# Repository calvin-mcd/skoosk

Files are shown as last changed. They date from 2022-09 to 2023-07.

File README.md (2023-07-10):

# skoosk

some kind of ortholinear split keyboard

The skoosk was my first attempt at creating a split ortholinear keyboard from scratch. The first production run had some issues with the pcb and the plate files. In the process of rectifying these issues I ended up creating simplifying the pcb for manual assembly. There are two different types of switch and backplates. One for more bounce, the other for more stability.

## Layout

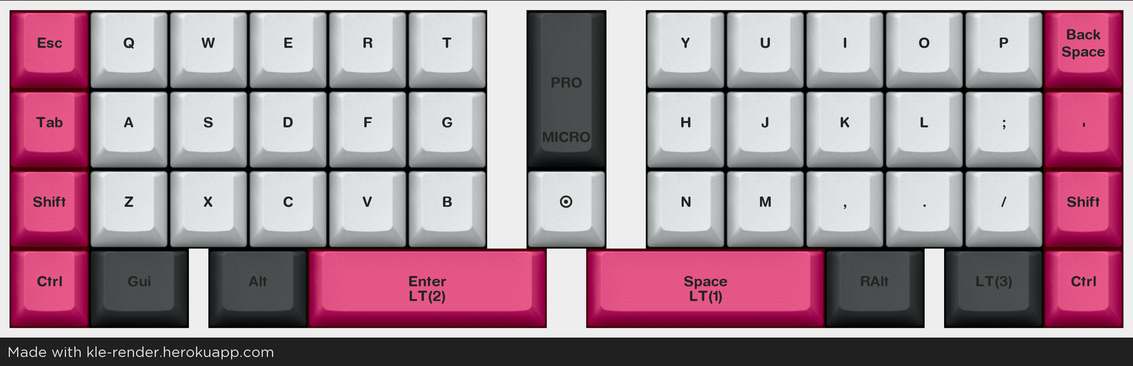
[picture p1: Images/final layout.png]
 

<a href="https://www.keyboard-layout-editor.com/#/gists/cdc0d16012a44037b1bdb8499f2bf92a">Link<a>

## Pictures

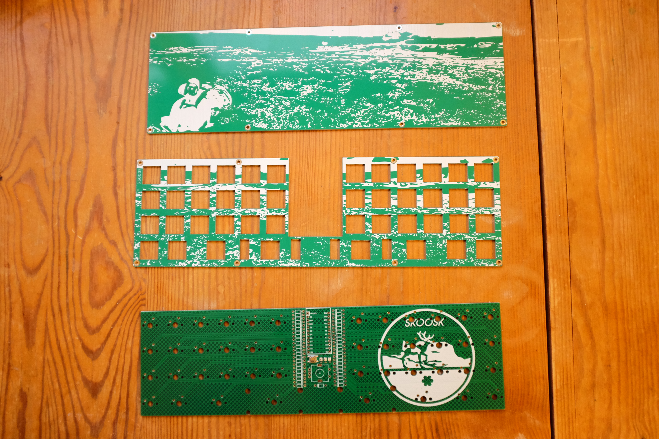
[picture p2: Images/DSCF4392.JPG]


## Project Files

*skoosk pcb rgb* is not designed for manual assembly supporting LEDs and a reset switch if wanted.

*skoosk switchplate & backplate 4 screwholes* each have 4 outer screwholes that give the sandwhich assembly a good amount of bounce.

*skoosk switchplate & backplate 8 screwholes* have 8 screwholes in total to offer more stability for the whole sandwhich case.

## Todo
- [ ] test newest pcb revision
- [ ] add firmware support for the RGB indicator leds

## Disclaimer

Please note that this project has not been tested in its final version. There are no guarantees of a working outcome. No-one involved in this project is responsible for any usage issues that may arise. However, feel free to edit, modify and otherwise utilise these files.

## License

This project is released under the GPL v3 License. Please refer to the LICENCE file.

## Credits

As always big thanks to the many people who helped me with the pcb, firmware and much more! 

Any questions, contact Calvin#0563 on Discord.

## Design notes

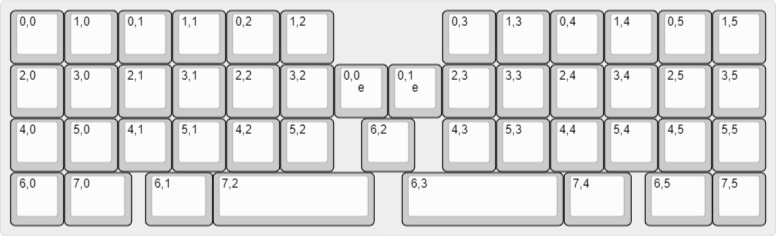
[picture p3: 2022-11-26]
Firmware/Images/updated-keyboard-layout.png

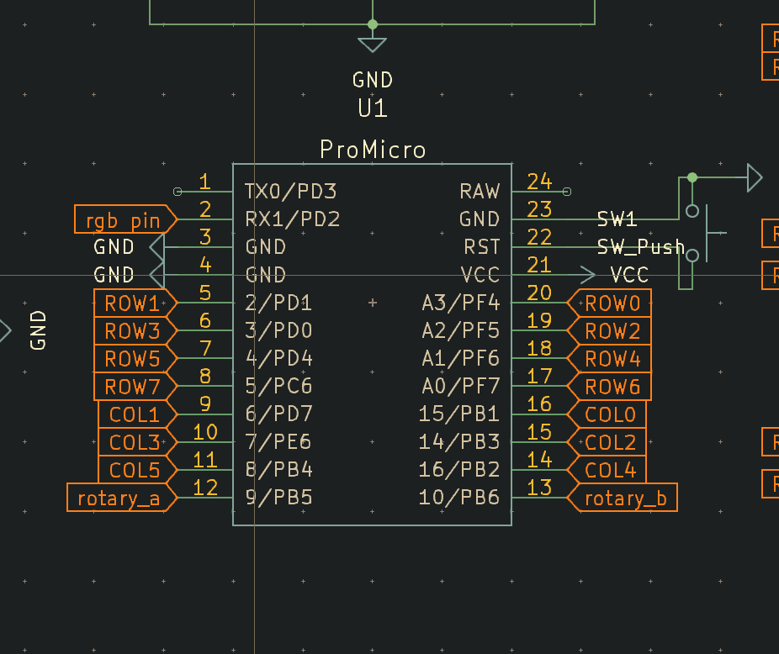
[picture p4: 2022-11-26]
Firmware/Images/mcu.png

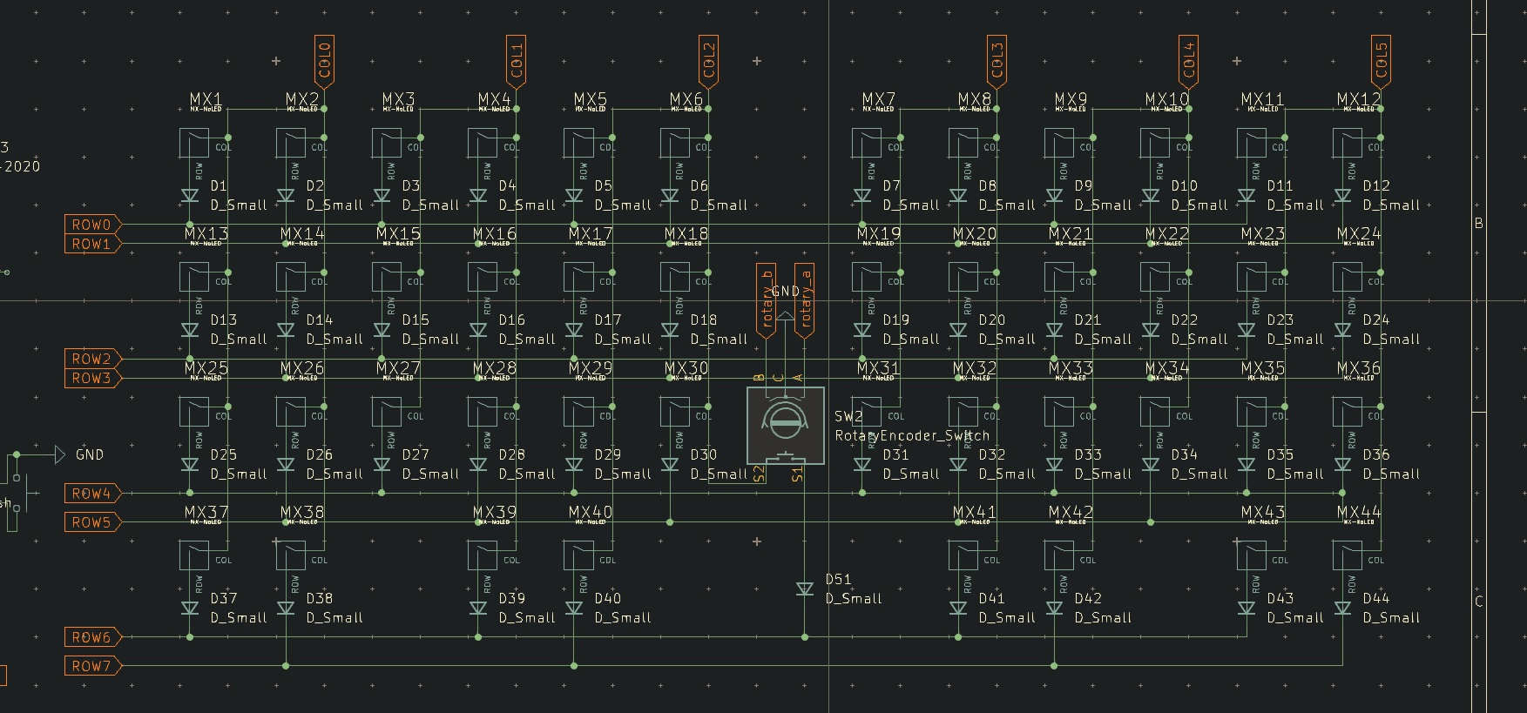
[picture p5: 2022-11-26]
Firmware/Images/matrix.jpg

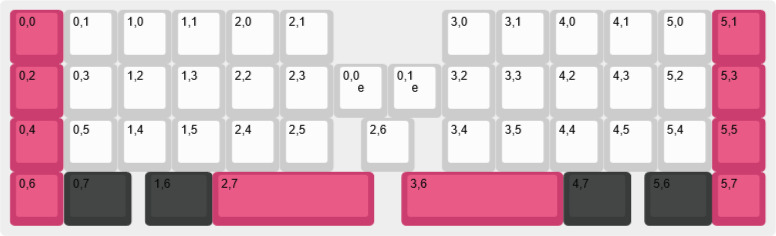
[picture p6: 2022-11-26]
Firmware/Images/keyboard-layout.jpg

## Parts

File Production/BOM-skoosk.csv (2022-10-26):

Comment | Designator | Footprint | LCSC
1uF | Crgb1,Crgb2,Crgb3 | C_0402_1005Metric | C14445
SW_Push | SW1 | SKQG-1155865 | C318884
WS2812-2020 | Drgb1,Drgb2,Drgb3 | WS2812-2020 | C965555

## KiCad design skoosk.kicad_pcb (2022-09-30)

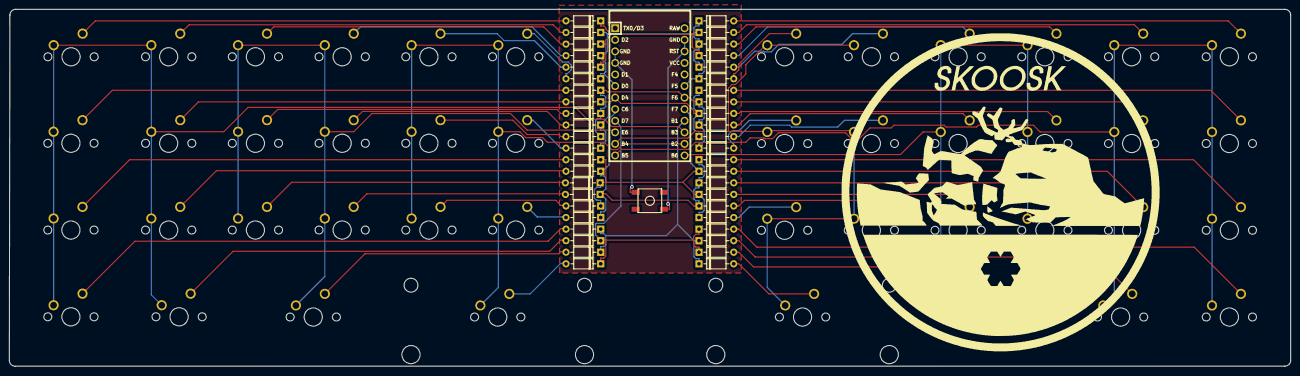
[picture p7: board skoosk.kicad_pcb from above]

Board: 2 copper layers, 281.4 x 78.4 mm, 92 parts (1 on the bottom side), 60 nets.

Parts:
D1, D2, D3, D4, D5, D6, D7, D8, D9, D10, D11, D12, D13, D14, D15, D16, D17, D18, D19, D20, D21, D22, D23, D24, D25, D26, D27, D28, D29, D30, D31, D32, D33, D34, D35, D36, D37, D38, D39, D40, D41, D42, D43, D44: D_Small; D_DO-35_SOD27_P7.62mm_Horizontal
Gback: LOGO
Gfront: LOGO
MX1, MX12, MX13, MX24, MX25, MX36, MX37, MX38, MX39, MX42, MX43, MX44: MX-NoLED; MXOnly-1.25U-NoLED
MX2, MX3, MX4, MX5, MX6, MX7, MX8, MX9, MX10, MX11, MX14, MX15, MX16, MX17, MX18, MX19, MX20, MX21, MX22, MX23, MX26, MX27, MX28, MX29, MX30, MX31, MX32, MX33, MX34, MX35: MX-NoLED; MXOnly-1U-NoLED
MX40, MX41: MX-NoLED; MXOnly-3U-NoLED
SW1: SW_Push; SKQG-1155865
U1: ProMicro; ArduinoProMicro

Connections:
COL0: MX1.1 (COL), MX2.1 (COL), MX13.1 (COL), MX14.1 (COL), MX25.1 (COL), MX26.1 (COL), MX37.1 (COL), MX38.1 (COL), U1.15 (14/PB3)
COL1: MX3.1 (COL), MX4.1 (COL), MX15.1 (COL), MX16.1 (COL), MX27.1 (COL), MX28.1 (COL), MX39.1 (COL), U1.10 (7/PE6)
COL2: MX5.1 (COL), MX6.1 (COL), MX17.1 (COL), MX18.1 (COL), MX29.1 (COL), MX30.1 (COL), MX40.1 (COL), U1.14 (16/PB2)
COL3: MX7.1 (COL), MX8.1 (COL), MX19.1 (COL), MX20.1 (COL), MX31.1 (COL), MX32.1 (COL), MX41.1 (COL), U1.11 (8/PB4)
COL4: MX9.1 (COL), MX10.1 (COL), MX21.1 (COL), MX22.1 (COL), MX33.1 (COL), MX34.1 (COL), MX42.1 (COL), U1.13 (10/PB6)
COL5: MX11.1 (COL), MX12.1 (COL), MX23.1 (COL), MX24.1 (COL), MX35.1 (COL), MX36.1 (COL), MX43.1 (COL), MX44.1 (COL), U1.12 (9/PB5)
GND: SW1.2, U1.3 (GND), U1.4 (GND)
unnamed: D1.2 (A), MX1.2 (ROW)
unnamed: D2.2 (A), MX2.2 (ROW)
unnamed: D3.2 (A), MX3.2 (ROW)
unnamed: D4.2 (A), MX4.2 (ROW)
unnamed: D5.2 (A), MX5.2 (ROW)
unnamed: D6.2 (A), MX6.2 (ROW)
unnamed: D7.2 (A), MX7.2 (ROW)
unnamed: D8.2 (A), MX8.2 (ROW)
unnamed: D9.2 (A), MX9.2 (ROW)
unnamed: D10.2 (A), MX10.2 (ROW)
unnamed: D11.2 (A), MX11.2 (ROW)
unnamed: D12.2 (A), MX12.2 (ROW)
unnamed: D13.2 (A), MX13.2 (ROW)
unnamed: D14.2 (A), MX14.2 (ROW)
unnamed: D15.2 (A), MX15.2 (ROW)
unnamed: D16.2 (A), MX16.2 (ROW)
unnamed: D17.2 (A), MX17.2 (ROW)
unnamed: D18.2 (A), MX18.2 (ROW)
unnamed: D19.2 (A), MX19.2 (ROW)
unnamed: D20.2 (A), MX20.2 (ROW)
unnamed: D21.2 (A), MX21.2 (ROW)
unnamed: D22.2 (A), MX22.2 (ROW)
unnamed: D23.2 (A), MX23.2 (ROW)
unnamed: D24.2 (A), MX24.2 (ROW)
unnamed: D25.2 (A), MX25.2 (ROW)
unnamed: D26.2 (A), MX26.2 (ROW)
unnamed: D27.2 (A), MX27.2 (ROW)
unnamed: D28.2 (A), MX28.2 (ROW)
unnamed: D29.2 (A), MX29.2 (ROW)
unnamed: D30.2 (A), MX30.2 (ROW)
unnamed: D31.2 (A), MX31.2 (ROW)
unnamed: D32.2 (A), MX32.2 (ROW)
unnamed: D33.2 (A), MX33.2 (ROW)
unnamed: D34.2 (A), MX34.2 (ROW)
unnamed: D35.2 (A), MX35.2 (ROW)
unnamed: D36.2 (A), MX36.2 (ROW)
unnamed: D37.2 (A), MX37.2 (ROW)
unnamed: D38.2 (A), MX38.2 (ROW)
unnamed: D39.2 (A), MX39.2 (ROW)
unnamed: D40.2 (A), MX40.2 (ROW)
unnamed: D41.2 (A), MX41.2 (ROW)
unnamed: D42.2 (A), MX42.2 (ROW)
unnamed: D43.2 (A), MX43.2 (ROW)
unnamed: D44.2 (A), MX44.2 (ROW)
unnamed: SW1.1, U1.22 (RST), U1.23 (GND)
ROW0: D1.1 (K), D3.1 (K), D5.1 (K), D7.1 (K), D9.1 (K), D11.1 (K), U1.19 (A2/PF5)
ROW1: D2.1 (K), D4.1 (K), D6.1 (K), D8.1 (K), D10.1 (K), D12.1 (K), U1.6 (3/PD0)
ROW2: D13.1 (K), D15.1 (K), D17.1 (K), D19.1 (K), D21.1 (K), D23.1 (K), U1.18 (A1/PF6)
ROW3: D14.1 (K), D16.1 (K), D18.1 (K), D20.1 (K), D22.1 (K), D24.1 (K), U1.7 (4/PD4)
ROW4: D25.1 (K), D27.1 (K), D29.1 (K), D31.1 (K), D33.1 (K), D35.1 (K), U1.17 (A0/PF7)
ROW5: D26.1 (K), D28.1 (K), D30.1 (K), D32.1 (K), D34.1 (K), D36.1 (K), U1.8 (5/PC6)
ROW6: D37.1 (K), D39.1 (K), D41.1 (K), D43.1 (K), U1.16 (15/PB1)
ROW7: D38.1 (K), D40.1 (K), D42.1 (K), D44.1 (K), U1.9 (6/PD7)

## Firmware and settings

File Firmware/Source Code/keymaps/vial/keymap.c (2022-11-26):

#include QMK_KEYBOARD_H

const uint16_t PROGMEM keymaps[][MATRIX_ROWS][MATRIX_COLS] = {
    [0] = LAYOUT(
        KC_NO,   KC_NO,   KC_NO,   KC_NO,   KC_NO,   KC_NO,
        KC_NO,   KC_NO,   KC_NO,   KC_NO,   KC_NO,   KC_NO,
        KC_NO,   KC_NO,   KC_NO,   KC_NO,   KC_NO,   KC_NO,
        KC_NO,   KC_NO,   KC_NO,   KC_NO,   KC_NO,   KC_NO,
        KC_NO,   KC_NO,   KC_NO,   KC_NO,   KC_NO,   KC_NO,
        KC_NO,   KC_NO,   KC_NO,   KC_NO,   KC_NO,   KC_NO,
        KC_NO,   KC_NO,   KC_NO,   KC_NO,            KC_NO,
        KC_NO,            KC_NO,            KC_NO,   KC_NO
    ),		
};

/* Encoder */ 
const uint16_t PROGMEM encoder_map[][NUM_ENCODERS][2] = {
    [0] = { ENCODER_CCW_CW(KC_TRNS, KC_TRNS) }
};

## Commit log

2022-09-29 Add submodules
    [skoosk.kicad_pcb, skoosk.kicad_sch]
2022-09-29 adding libraries
    [skoosk.kicad_sch]
2022-09-29 switch matrix build, footprints layed out
    missing is MCU footprint, reset switch, traces
    do i want underglow?
    [skoosk.kicad_pcb, skoosk.kicad_sch]
2022-09-29 all switches and diodes placed
    next change mcu for usb c, figure out a reset button
    [skoosk.kicad_pcb, skoosk.kicad_sch]
2022-09-29 tracing col and rows
    [skoosk.kicad_pcb, skoosk.kicad_sch]
2022-09-30 saving before doing autorouting
    [skoosk.kicad_pcb, skoosk.kicad_sch]
2022-09-30 added silkscreen, protective layer, auto tracing
    auto tracing still needs to be confirmed working
    [skoosk.dsn, skoosk.kicad_pcb, skoosk.kicad_sch]
2022-09-30 zero error return
    add some led?
    get feedback?
    [skoosk.kicad_pcb]
2022-09-30 GND filling done, added some ideas
    maybe a rotary encoder and rgd leds?
    [skoosk.kicad_sch]
2022-10-01 ordering schematics to add rotary and rgd
    [skoosk.kicad_sch]
2022-10-01 added rotary and rgb to schematics and editor
    not yet fully confirmed to be working correctly
    [skoosk.kicad_sch]
2022-10-01 rotary schematics updated, smd capacitors chosen for rgb
    [skoosk.kicad_sch]
2022-10-01 fixed schematics
    new routing to be done
    [skoosk.kicad_sch]
2022-10-01 final fix to schematic
    noah approved
    [skoosk.kicad_sch]
2022-10-02 completed schematics & pcb
    no error messages
    [skoosk.dsn]
2022-10-02 first draft, no mounting holes
    [skoosk backplate.kicad_pcb, skoosk switchplate.kicad_pcb]
2022-10-06 changed layout for pcb, switch and backplate. added curved routes
    [skoosk 1u.dsn, skoosk backplate.kicad_pcb, skoosk switchplate.kicad_pcb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]
2022-10-06 mounting holes added
    [backplate.kicad_pcb, skoosk backplate.kicad_pcb, skoosk.dsn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]
2022-10-06 cleaned switchplate, added holes to pcb and backplate
    [backplate.kicad_pcb, skoosk 1u.dsn, skoosk switchplate.kicad_pcb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]
2022-10-07 finalising pcb, backplate, switchplate. cleaning up redundant files
2022-10-08 cleaned up pcb and switchplate
2022-10-09 created gerbers for pcb, switch and backplate
    [skoosk backplate-B_Cu.gbr, skoosk backplate-B_Mask.gbr, skoosk backplate-B_Paste.gbr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]
2022-10-11 generated gerbers, tried to fill in parts
    [skoosk backplate-B_Cu.gbr, skoosk backplate-B_Mask.gbr, skoosk backplate-B_Paste.gbr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]
2022-10-20 cleaned up pcb, switch & backplate
    [skoosk backplate.kicad_pcb, skoosk switchplate.kicad_pcb, skoosk.dsn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]
2022-10-24 cleaning up
    changed pcb size, for mounting
    flipped stabs on plate and pcb
    changed clearance on copper fill
    [skoosk switchplate.kicad_pcb, skoosk.kicad_sch]
2022-10-25 pcb, plate edge cuts changed
    [skoosk backplate.kicad_pcb, skoosk switchplate.kicad_pcb, skoosk.kicad_sch]
2022-10-25 zero drc errors, gerber, drill created
    [skoosk backplate-B_Cu.gbr, skoosk backplate-B_Mask.gbr, skoosk backplate-B_Paste.gbr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]
2022-10-25 created production files for all parts
    parts list stilll missing
    [skoosk backplate-B_Cu.gbr, skoosk backplate-B_Mask.gbr, skoosk backplate-B_Silkscreen.gbr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]
2022-10-26 created jlc production files
    [BOM-skoosk.csv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]
2022-11-08 fixed plates with v1.1, slight rerouting for visual consistency on pcb
    [BOM-skoosk.csv, freerouting.dsn, skoosk backplate v1.1.kicad_pcb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]
2022-11-21 cleaned up plate files and options
    [freerouting.dsn, skoosk acrylic layer top-B_Cu.dxf, skoosk acrylic layer top-Edge_Cuts.dxf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]
2022-11-26 repairing schematics, changing pcb
    [BOM-skoosk pcb no leds rgb.csv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]
2022-12-17 clean up
    [BOM-skoosk pcb no leds rgb.csv, skoosk backplate 4 screwholes.kicad_pcb, skoosk backplate 8 screwholes.kicad_pcb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]
2023-01-10 readme update
    [BOM-skoosk pcb no leds rgb.csv, skoosk acrylic layer top-B_Cu.dxf, skoosk acrylic layer top-Edge_Cuts.dxf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]
2023-07-10 single pcb version, simplifying project
    [skoosk backplate 4 screwholes.kicad_pcb, skoosk backplate 8 screwholes.kicad_pcb, skoosk pcb rgb.kicad_sch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]
